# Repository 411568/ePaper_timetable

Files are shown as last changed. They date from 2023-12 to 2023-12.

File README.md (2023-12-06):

# ePaper_timetable
Project for Design Laboratory - Systems and Networks Laboratory 

## Authors
Jakub Bulik
Marek Pawłowski
Krzysztof Sikora

TODO: 
* dodac zlacze zasilajace (usb?)
* sprawdzic schemat
* dodac pozostale footprinty
* dodac model 3d pi pico (nie chce mi dzialac bo to jakis dziwny format)
* ogarnac jakis model 3d wyswietlacza

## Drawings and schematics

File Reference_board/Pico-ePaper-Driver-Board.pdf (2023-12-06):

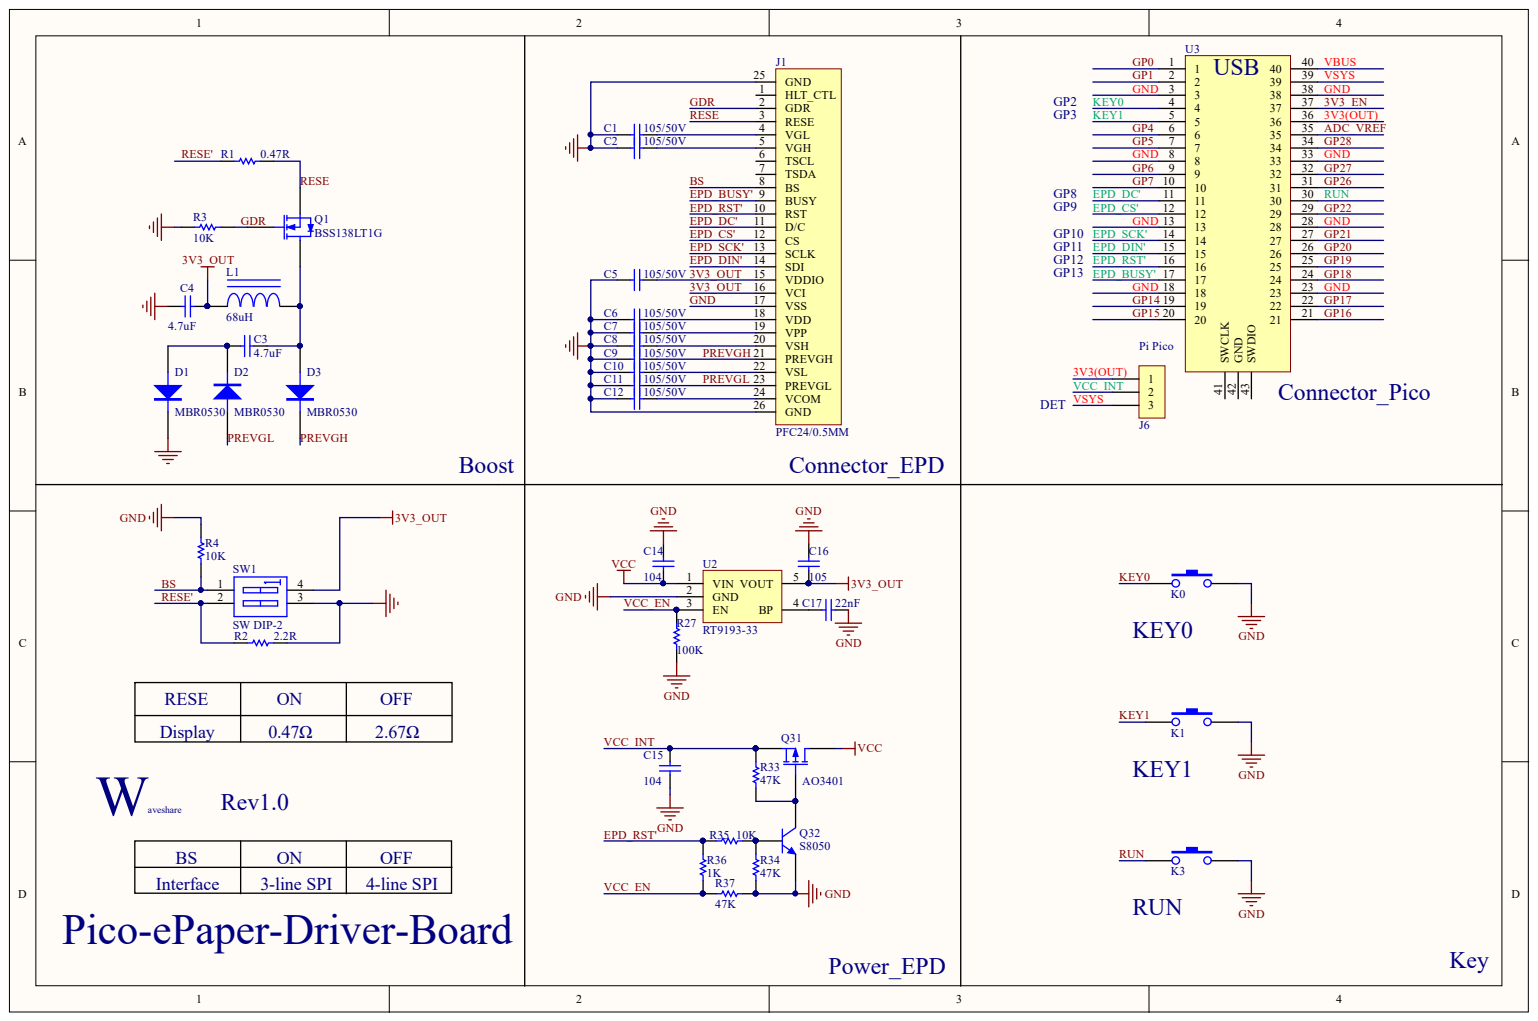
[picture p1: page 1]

Pi Pico GP0 GP1 GND GP4 GP5 GND GND GND

C7 | | 1 0 5 / 5 0 V 1 9
C8 | | 1 0 5 / 5 0 V 2 0

C1 0 | 1 0 5 / 5 0 V 2
C1 1 | 1 0 5 / 5 0 V PRE V G L 2 3
C1 2 | 1 0 5 / 5 0 V 2

BS | O N | OFF
Interface | 3-line SPI | 4-line SPI

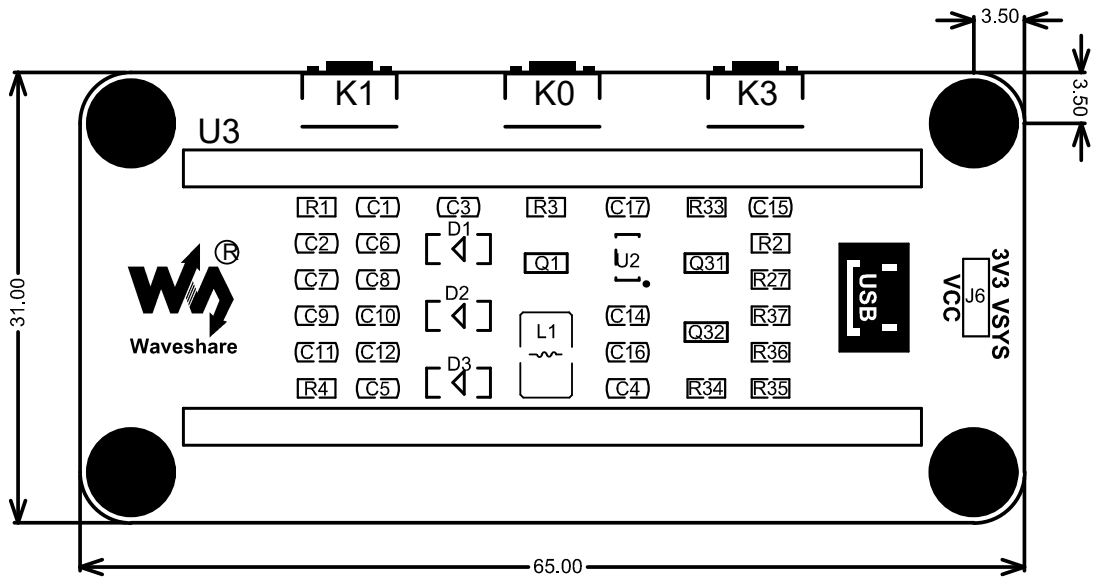
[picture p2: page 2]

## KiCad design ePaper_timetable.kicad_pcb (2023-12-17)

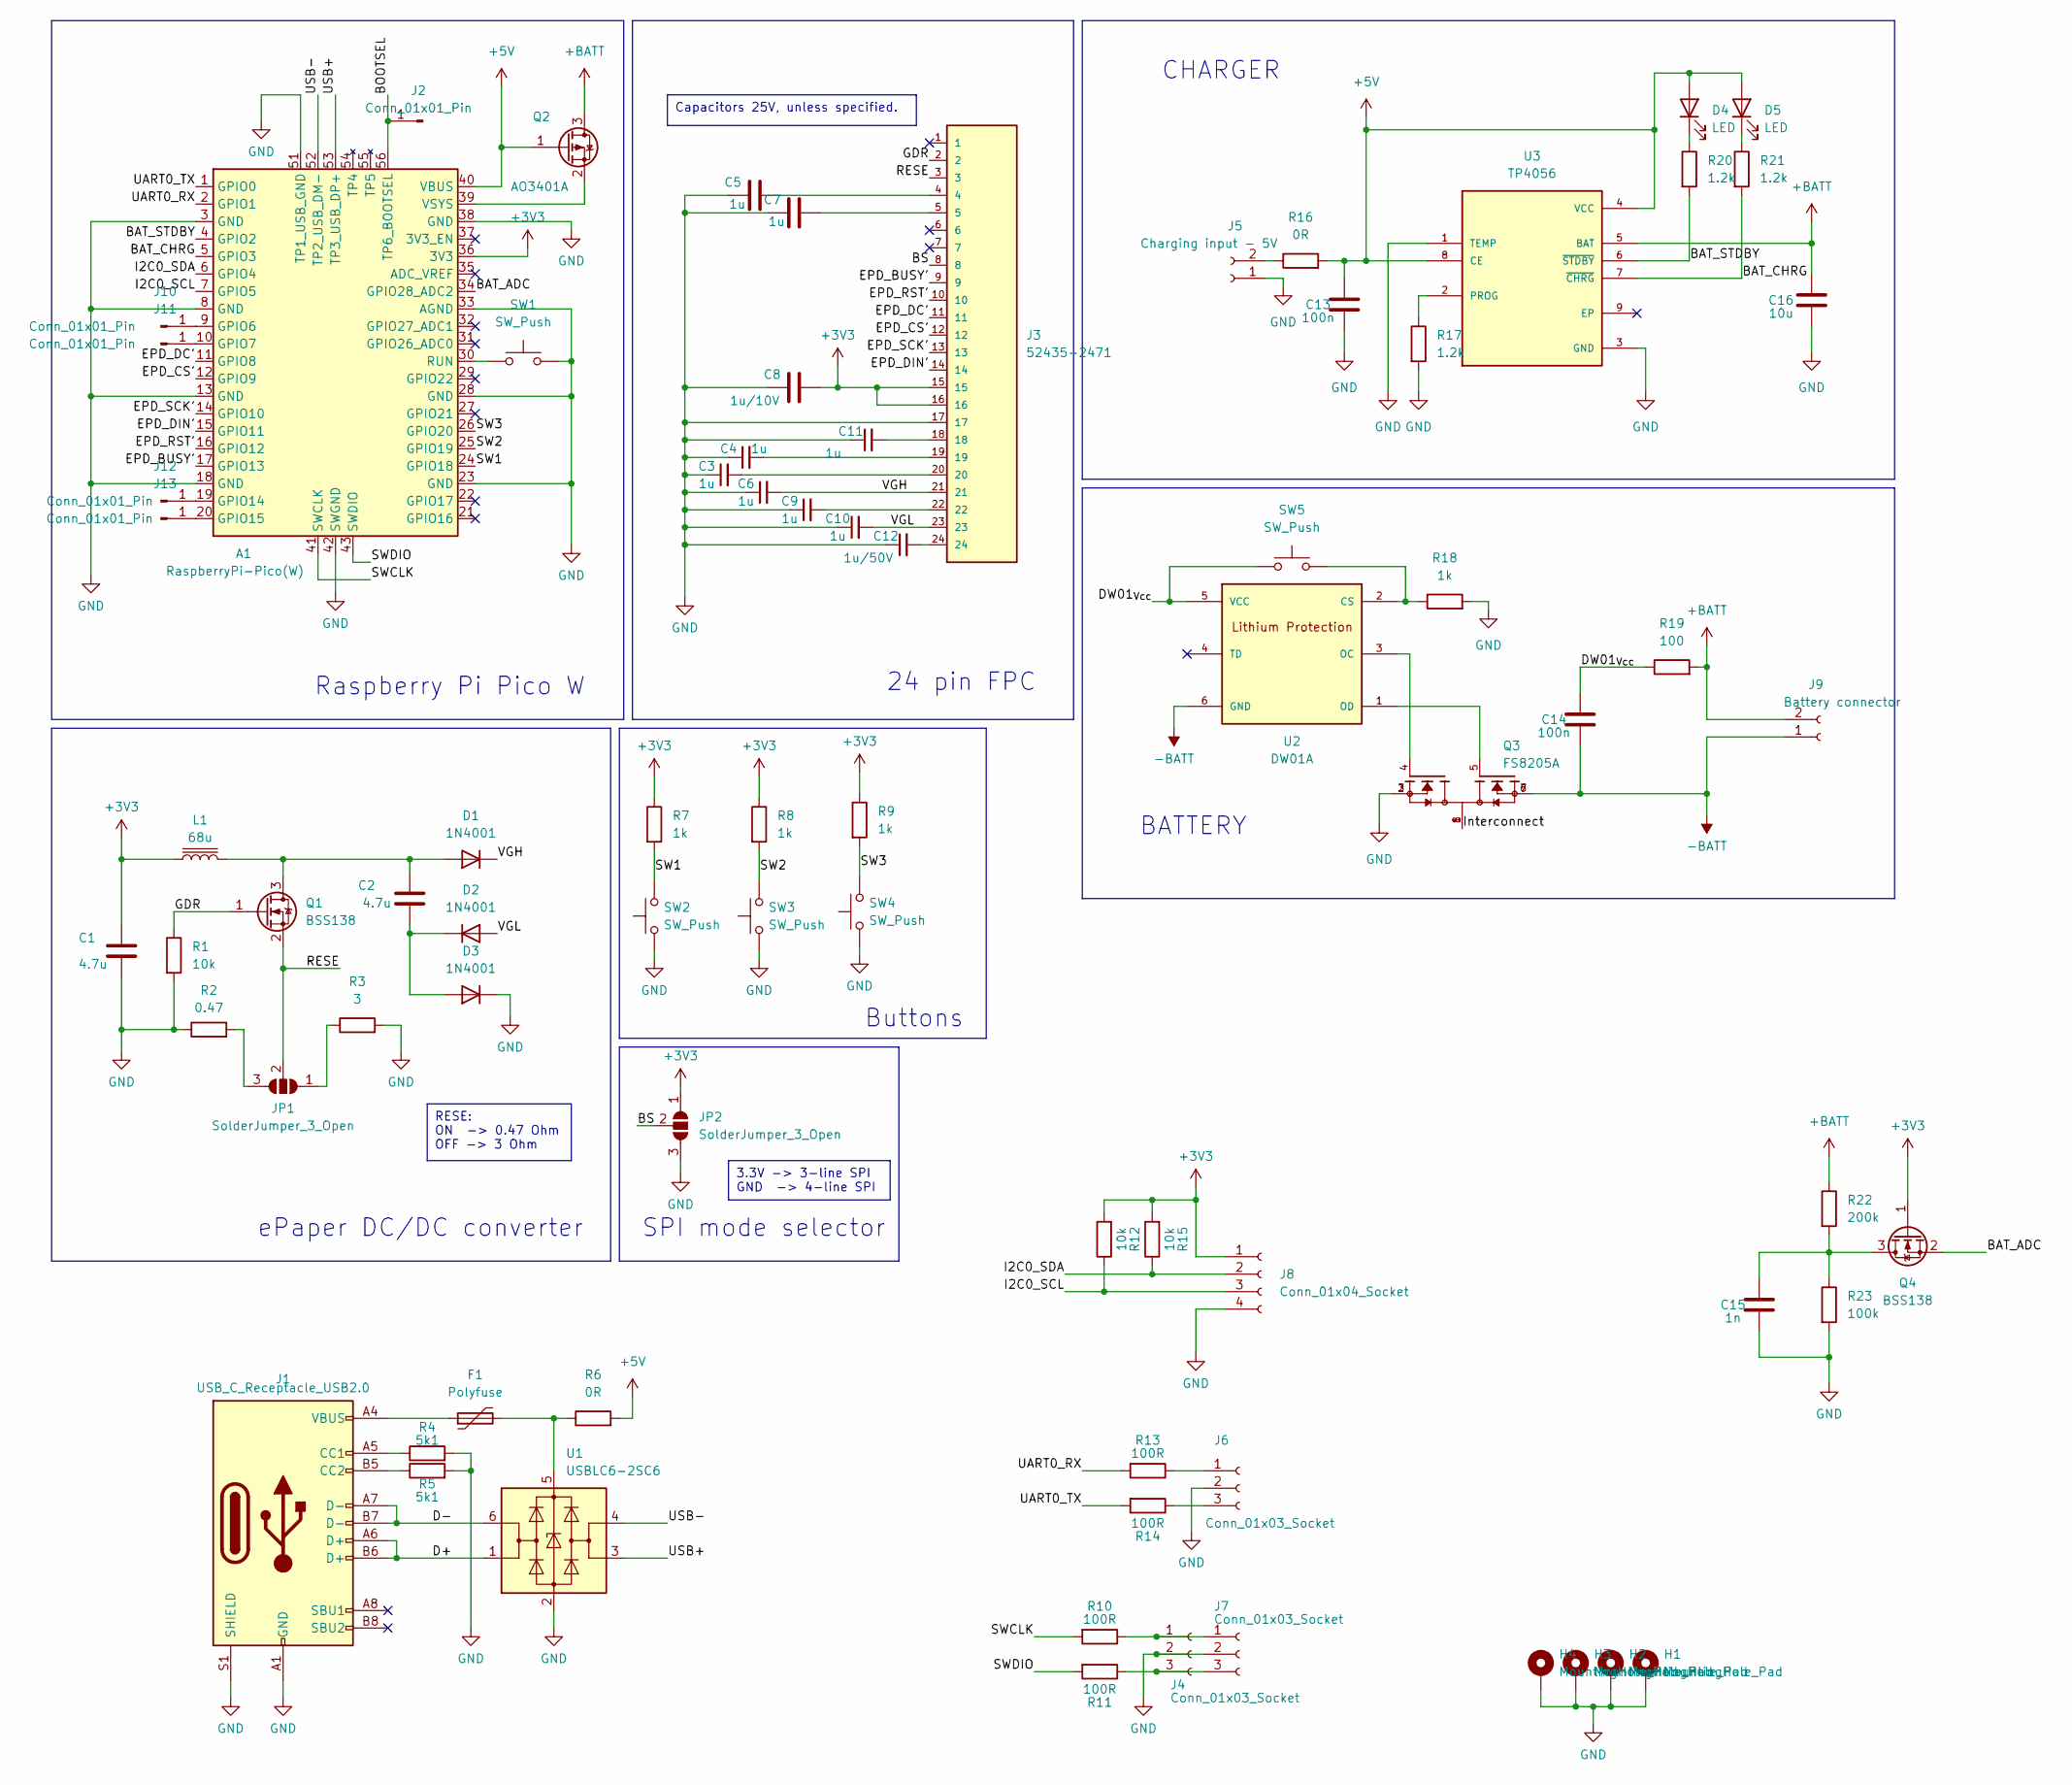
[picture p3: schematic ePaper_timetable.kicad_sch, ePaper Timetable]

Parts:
A1: RaspberryPi-Pico(W); Raspberry_Pi_Pico_W_SMT
C1, C2: 4.7u; C_0805_2012Metric_Pad1.18x1.45mm_HandSolder
C3, C4, C5, C6, C7, C9, C10, C11: 1u; C_0805_2012Metric_Pad1.18x1.45mm_HandSolder
C8: 1u/10V; C_0805_2012Metric_Pad1.18x1.45mm_HandSolder
C12: 1u/50V; C_0805_2012Metric_Pad1.18x1.45mm_HandSolder
C13, C14: 100n; C_0805_2012Metric_Pad1.18x1.45mm_HandSolder
C15: 1n; C_0805_2012Metric_Pad1.18x1.45mm_HandSolder
C16: 10u; C_0805_2012Metric_Pad1.18x1.45mm_HandSolder
D1, D2, D3: 1N4001; D_SOD-123
D4, D5: LED; LED_0805_2012Metric_Pad1.15x1.40mm_HandSolder
F1: Polyfuse; Fuse_1812_4532Metric_Pad1.30x3.40mm_HandSolder
H1, H2, H3, H4: MountingHole_Pad; MountingHole_3.2mm_M3_Pad
J1: USB_C_Receptacle_USB2.0; USB_C_Receptacle_GCT_USB4105-xx-A_16P_TopMnt_Horizontal
J2, J10, J11, J12, J13: Conn_01x01_Pin; SolderWirePad_1x01_SMD_1x2mm
J3: 52435-2471; MOLEX_52435-2471
J4, J6: Conn_01x03_Socket; PinSocket_1x03_P2.54mm_Vertical
J5: Charging input - 5V; PhoenixContact_MC_1,5_2-G-3.81_1x02_P3.81mm_Horizontal
J7: Conn_01x03_Socket; JST_SH_BM03B-SRSS-TB_1x03-1MP_P1.00mm_Vertical
J8: Conn_01x04_Socket; PinSocket_1x04_P2.54mm_Vertical
J9: Battery connector; PinSocket_1x02_P2.54mm_Vertical
JP1, JP2: SolderJumper_3_Open; SolderJumper-3_P1.3mm_Open_RoundedPad1.0x1.5mm_NumberLabels
L1: 68u; L_Changjiang_FNR6045S
Q1, Q4: BSS138; SOT-23
Q2: AO3401A; SOT-23
Q3: FS8205A; TSSOP-8_4.4x3mm_P0.65mm; PARTREV 1.7
R1, R12, R15: 10k; R_0805_2012Metric_Pad1.20x1.40mm_HandSolder
R2: 0.47; R_0805_2012Metric_Pad1.20x1.40mm_HandSolder
R3: 3; R_0805_2012Metric_Pad1.20x1.40mm_HandSolder
R4, R5: 5k1; R_0805_2012Metric_Pad1.20x1.40mm_HandSolder
R6, R16: 0R; R_1206_3216Metric_Pad1.30x1.75mm_HandSolder
R7, R8, R9, R18: 1k; R_0805_2012Metric_Pad1.20x1.40mm_HandSolder
R10, R11, R13, R14: 100R; R_0805_2012Metric_Pad1.20x1.40mm_HandSolder
R17, R20, R21: 1.2k; R_0805_2012Metric_Pad1.20x1.40mm_HandSolder
R19: 100; R_0805_2012Metric_Pad1.20x1.40mm_HandSolder
R22: 200k; R_0805_2012Metric_Pad1.20x1.40mm_HandSolder
R23: 100k; R_0805_2012Metric_Pad1.20x1.40mm_HandSolder
SW1, SW5: SW_Push; SW_Tactile_SPST_NO_Straight_CK_PTS636Sx25SMTRLFS
SW2, SW3, SW4: SW_Push; SW_PUSH_6mm_H7.3mm
U1: USBLC6-2SC6; SOT-23-6
U2: DW01A; SOT-23-6_Handsoldering; M_PART_NUMBER DW01A
U3: TP4056; HTSOP-8-1EP_3.9x4.9mm_P1.27mm_EP2.4x3.2mm

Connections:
+3V3: A1.36 (3V3), C1.2, C8.2, J3.15, J3.16, J8.1, JP2.1 (A), L1.1, Q4.1 (G), R7.1, R8.1, R9.1, R12.2, R15.2
+5V: A1.40 (VBUS), C13.2, D4.2 (A), D5.2 (A), Q2.1 (G), R6.2, R16.2, U3.4 (VCC), U3.8 (CE)
+BATT: C16.2, J9.2, Q2.3 (D), R19.2, R22.1, U3.5 (BAT)
-BATT: C14.1, J9.1, Q3.6, Q3.7, U2.6 (GND)
/BAT_ADC: A1.34 (GPIO28_ADC2), Q4.2 (S)
/BAT_CHRG: A1.5 (GPIO3), R21.2, U3.7 (~CHRG)
/BAT_STDBY: A1.4 (GPIO2), R20.2, U3.6 (~STDBY)
/BOOTSEL: A1.56 (TP6_BOOTSEL), J2.1
/BS: J3.8, JP2.2 (C)
/D+: J1.A6 (D+), J1.B6 (D+), U1.1 (I/O1)
/D-: J1.A7 (D-), J1.B7 (D-), U1.6 (I/O1)
/DW01_{Vcc}: C14.2, R19.1, SW5.1, U2.5 (VCC)
/EPD_BUSY': A1.17 (GPIO13), J3.9
/EPD_CS': A1.12 (GPIO9), J3.12
/EPD_DC': A1.11 (GPIO8), J3.11
/EPD_DIN': A1.15 (GPIO11), J3.14
/EPD_RST': A1.16 (GPIO12), J3.10
/EPD_SCK': A1.14 (GPIO10), J3.13
/GDR: J3.2, Q1.1 (G), R1.1
/I2C0_SCL: A1.7 (GPIO5), J8.3, R12.1
/I2C0_SDA: A1.6 (GPIO4), J8.2, R15.1
/Interconnect: Q3.1, Q3.8
/RESE: J3.3, JP1.2 (C), Q1.2 (S)
/SW1: A1.24 (GPIO18), R7.2, SW2.2
/SW2: A1.25 (GPIO19), R8.2, SW3.2
/SW3: A1.26 (GPIO20), R9.2, SW4.2
/SWCLK: A1.41 (SWCLK), R10.2
/SWDIO: A1.43 (SWDIO), R11.2
/UART0_RX: A1.2 (GPIO1), R13.2
/UART0_TX: A1.1 (GPIO0), R14.2
/USB+: A1.53 (TP3_USB_DP+), U1.3 (I/O2)
/USB-: A1.52 (TP2_USB_DM-), U1.4 (I/O2)
/VGH: C6.2, D1.1 (K), J3.21
/VGL: C10.2, D2.2 (A), J3.23
GND: A1.3 (GND), A1.8 (GND), A1.13 (GND), A1.18 (GND), A1.23 (GND), A1.28 (GND), A1.33 (AGND), A1.38 (GND), A1.42 (SWGND), A1.51 (TP1_USB_GND), C1.1, C3.1, C4.1, C5.1, C6.1, C7.1, C8.1, C9.1, C10.1, C11.1, C12.1, C13.1, C15.1, C16.1, D3.1 (K), H1.1, H2.1, H3.1, H4.1, J1.A1 (GND), J1.A12 (GND), J1.B1 (GND), J1.B12 (GND), J1.S1 (SHIELD), J3.17, J4.2, J5.1, J6.2, J7.2, J8.4, JP2.3 (B), Q3.2, Q3.3, R1.2, R2.1, R3.2, R4.2, R5.2, R17.2, R18.2, R23.2, SW1.2, SW2.1, SW3.1, SW4.1, U1.2 (GND), U3.1 (TEMP), U3.3 (GND)
unnamed: A1.9 (GPIO6), J10.1
unnamed: A1.10 (GPIO7), J11.1
unnamed: A1.19 (GPIO14), J12.1
unnamed: A1.20 (GPIO15), J13.1
unnamed: A1.30 (RUN), SW1.1
unnamed: A1.39 (VSYS), Q2.2 (S)
unnamed: C3.2, J3.20
unnamed: C4.2, J3.19
unnamed: C5.2, J3.4
unnamed: C7.2, J3.5
unnamed: C9.2, J3.22
unnamed: C11.2, J3.18
unnamed: C12.2, J3.24
unnamed: C2.2, D1.2 (A), L1.2, Q1.3 (D)
unnamed: C2.1, D2.1 (K), D3.2 (A)
unnamed: D4.1 (K), R20.1
unnamed: D5.1 (K), R21.1
unnamed: F1.1, J1.A4 (VBUS), J1.A9 (VBUS), J1.B4 (VBUS), J1.B9 (VBUS)
unnamed: J1.A5 (CC1), R4.1
unnamed: J1.B5 (CC2), R5.1
unnamed: J4.1, J7.1, R10.1
unnamed: J4.3, J7.3, R11.1
unnamed: J5.2, R16.1
unnamed: J6.1, R13.1
unnamed: J6.3, R14.1
unnamed: JP1.1 (A), R3.1
unnamed: JP1.3 (B), R2.2
unnamed: C15.2, Q4.3 (D), R22.2, R23.1
unnamed: F1.2, R6.1, U1.5 (VBUS)
unnamed: R18.1, SW5.2, U2.2 (CS)
unnamed: Q3.4, U2.3 (OC)
unnamed: Q3.5, U2.1 (OD)
unnamed: R17.1, U3.2 (PROG)

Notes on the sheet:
Capacitors 25V, unless specified.
3.3V -> 3-line SPI GND -> 4-line SPI
RESE: ON -> 0.47 Ohm OFF -> 3 Ohm
CHARGER
ePaper DC/DC converter
SPI mode selector
24 pin FPC
BATTERY
Raspberry Pi Pico W
Buttons

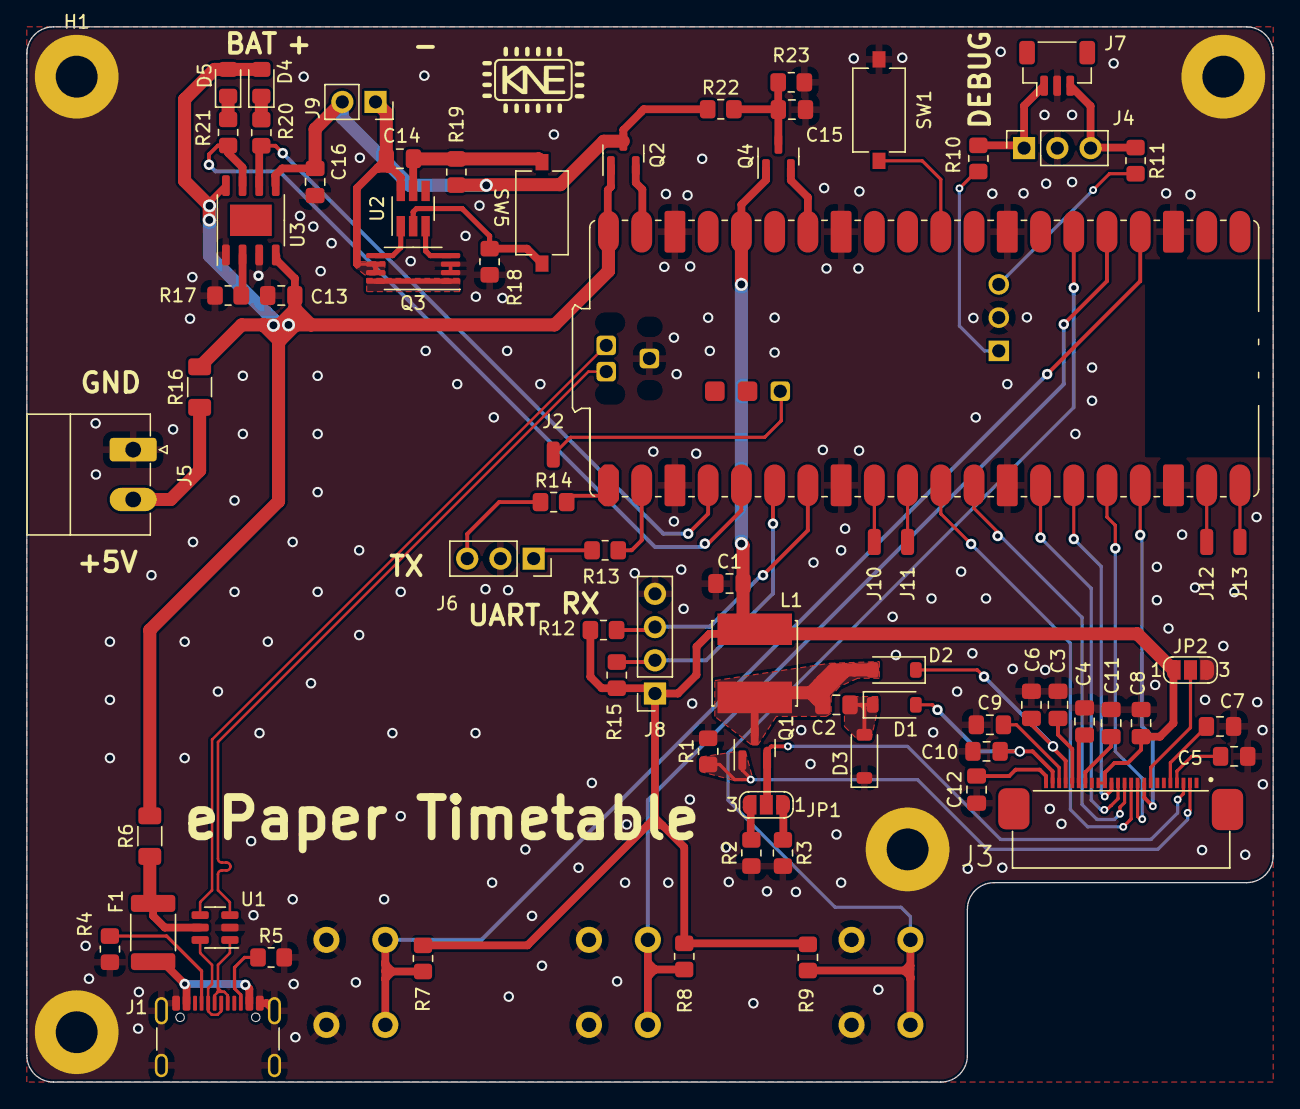
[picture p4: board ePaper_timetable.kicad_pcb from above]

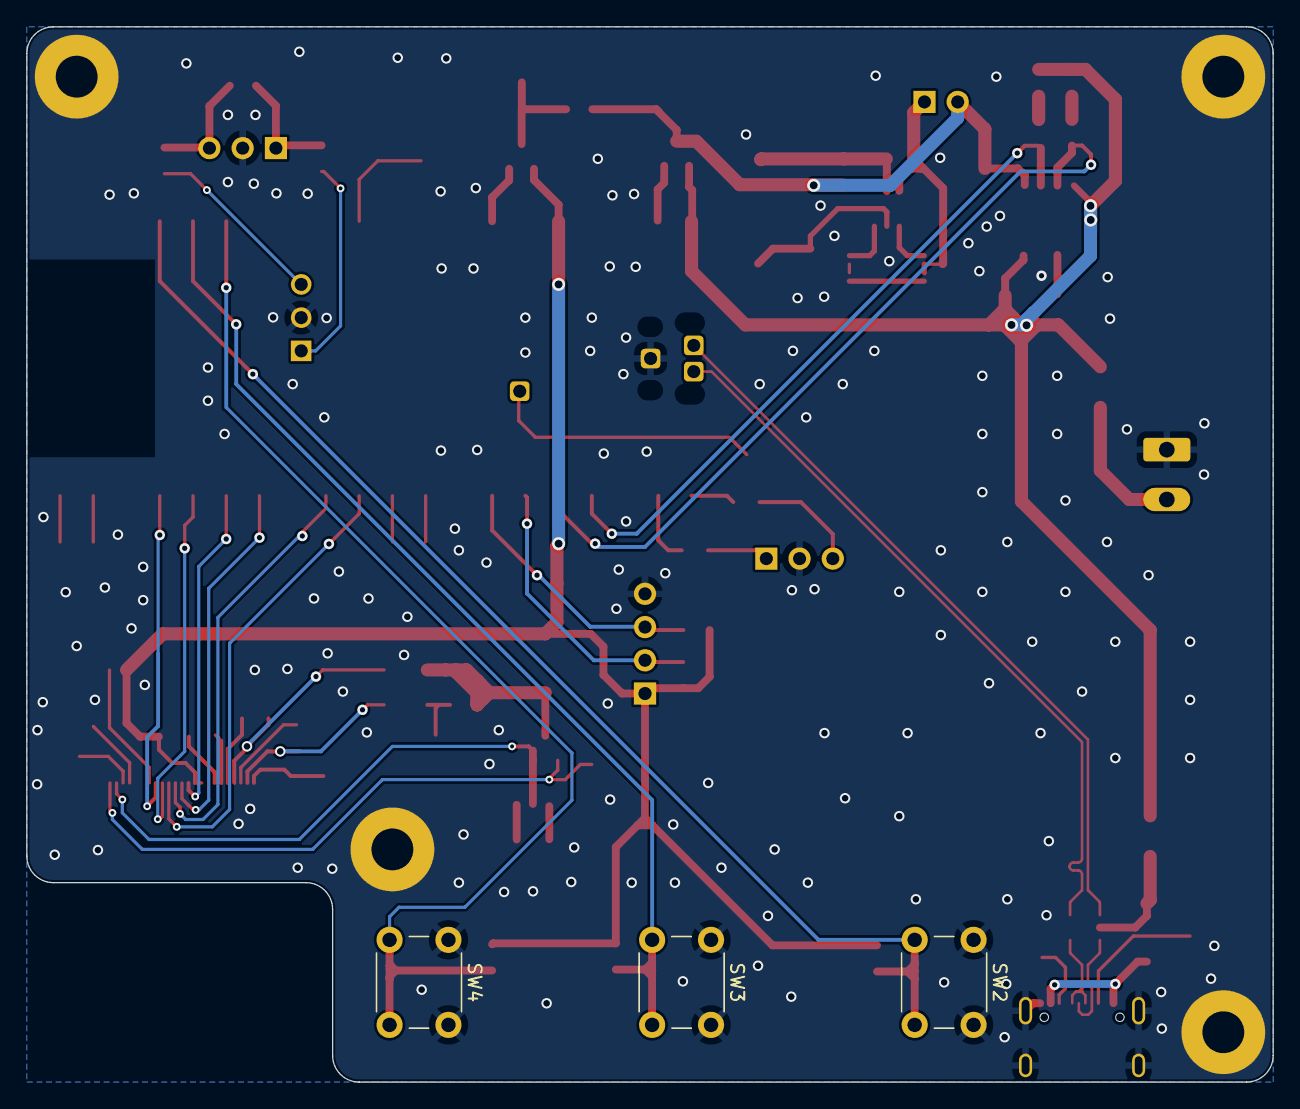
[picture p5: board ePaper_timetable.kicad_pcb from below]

Board: 2 copper layers, 95.2 x 80.6 mm, 78 parts (3 on the bottom side), 68 nets.

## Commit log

2023-11-29 kicad project
    [ePaper_timetable.kicad_pcb, ePaper_timetable.kicad_sch]
2023-11-29 first schematic
    [ePaper_timetable.kicad_sch]
2023-12-06 reference board
    [ePaper_timetable.kicad_sch]
2023-12-06 schematic update: added footprints
    [ePaper_timetable.kicad_sch]
2023-12-06 charging circuit footprints added
    [ePaper_timetable.kicad_pcb, ePaper_timetable.kicad_sch]
2023-12-06 display 3d model added
    [ePaper_timetable.kicad_pcb]
2023-12-06 Adding FPC footprints libraries.
    [ePaper_timetable.kicad_sch]
2023-12-06 fixed pcb - not saved previously
    [ePaper_timetable.kicad_pcb]
2023-12-08 update sch and lib
    [ePaper_timetable.kicad_sch]
2023-12-08 update sch and pcb
    [ePaper_timetable.kicad_pcb, ePaper_timetable.kicad_sch]
2023-12-14 fpc connector fix
    [ePaper_timetable.kicad_pcb, ePaper_timetable.kicad_sch]
2023-12-14 layout started
    [ePaper_timetable.kicad_pcb]
2023-12-15 layout proposition
    [ePaper_timetable.kicad_pcb, ePaper_timetable.kicad_sch]
2023-12-16 prepared for review
    [ePaper_timetable.kicad_pcb]
2023-12-17 minor changes
    [ePaper_timetable.kicad_pcb]
2023-12-17 gerbers generated
    [ePaper_timetable-B_Cu.gbl, ePaper_timetable-B_Mask.gbs, ePaper_timetable-B_Paste.gbp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]
2023-12-21 move gerber files
    [ePaper_timetable-B_Cu.gbl, ePaper_timetable-B_Mask.gbs, ePaper_timetable-B_Paste.gbp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]
